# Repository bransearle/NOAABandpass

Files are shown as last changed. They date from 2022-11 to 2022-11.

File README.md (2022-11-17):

# NOAABandpass

A bandpass filter & bias-T powered LNA for receiving APT & LRPT satellite images in the 137MHz region.

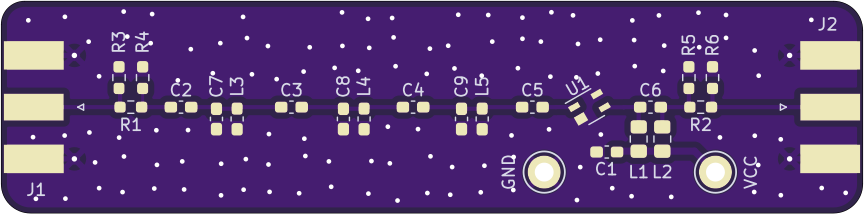
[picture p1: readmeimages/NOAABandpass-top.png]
PCB top side

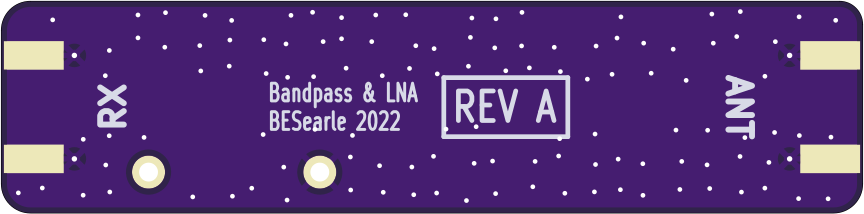
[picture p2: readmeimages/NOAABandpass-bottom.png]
PCB underside


The design uses a 3rd-order Butterworth capacitively-coupled LC resonator filter, followed by a Mini-Circuits MMIC preamp.

Supply voltage is 3V-5V to the bias T. 

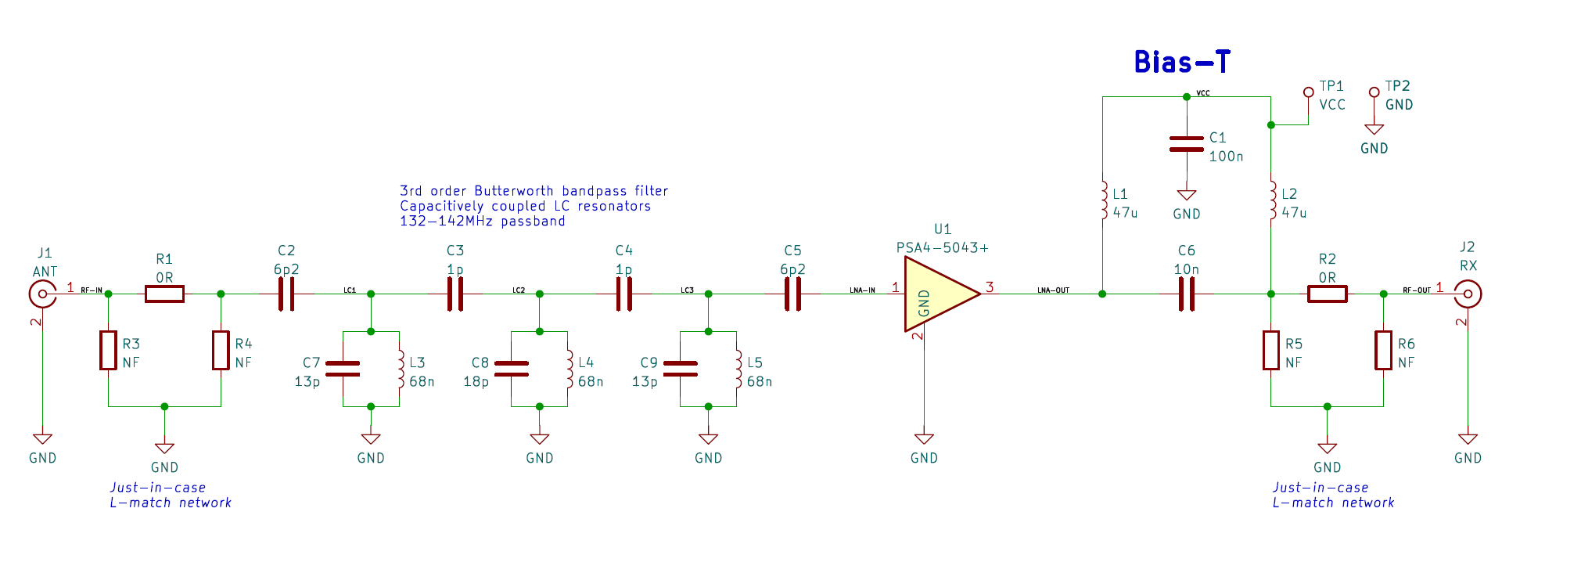
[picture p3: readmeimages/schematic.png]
Schematic

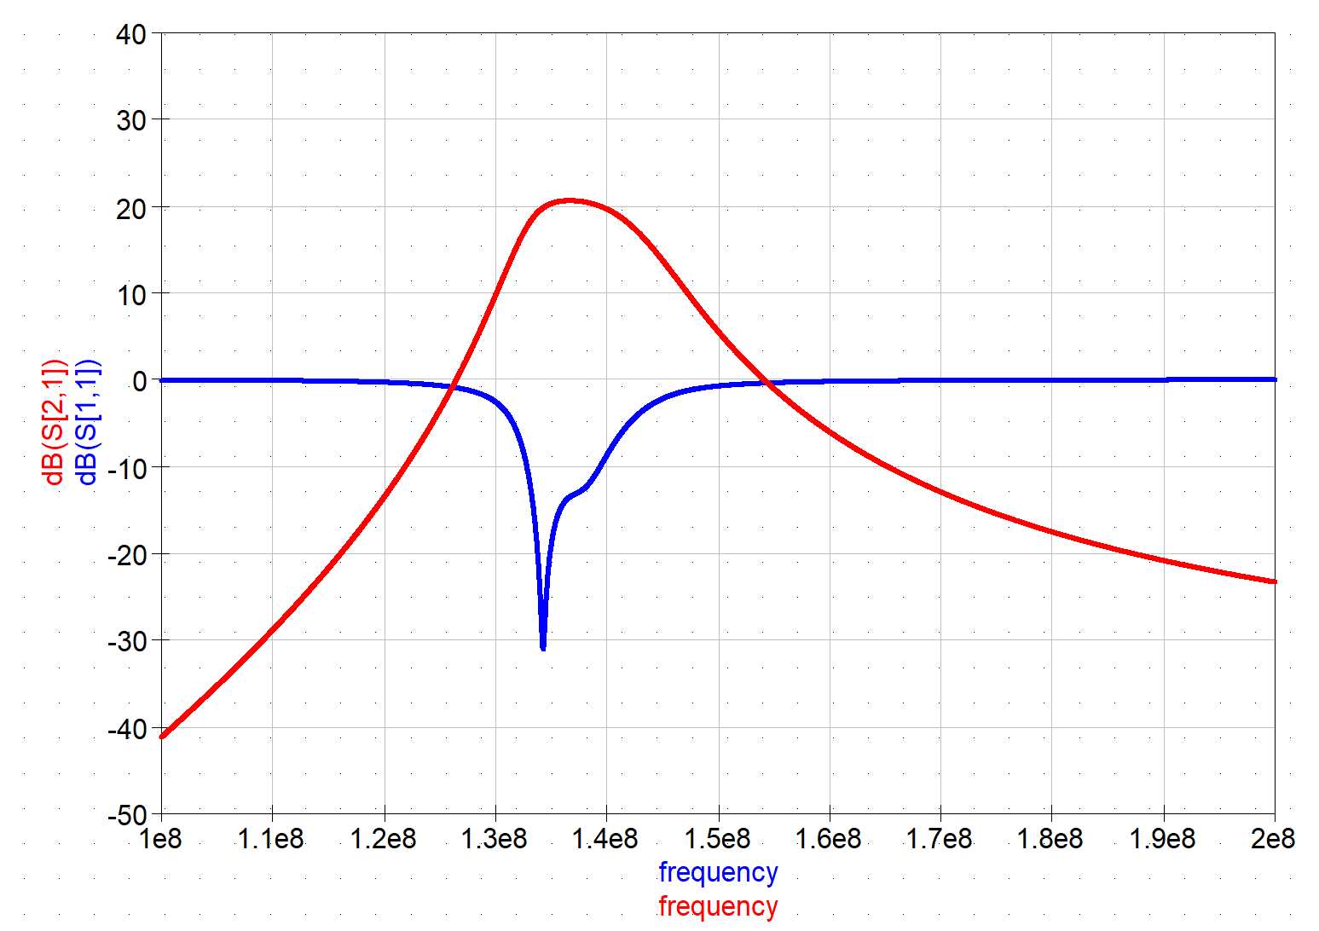
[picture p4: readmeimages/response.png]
Filter response


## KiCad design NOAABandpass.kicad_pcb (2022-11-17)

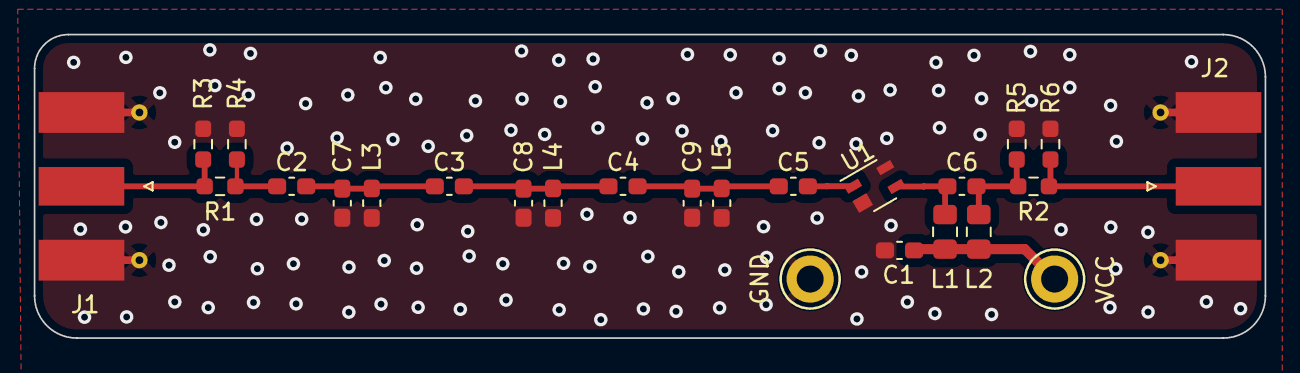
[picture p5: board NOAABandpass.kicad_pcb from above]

Board: 4 copper layers, 73.0 x 18.0 mm, 25 parts (0 on the bottom side), 11 nets.

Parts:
C1: 100n; C_0603_1608Metric_Pad1.08x0.95mm_HandSolder
C2, C5: 6p2; C_0603_1608Metric_Pad1.08x0.95mm_HandSolder
C3, C4: 1p; C_0603_1608Metric_Pad1.08x0.95mm_HandSolder
C6: 10n; C_0603_1608Metric_Pad1.08x0.95mm_HandSolder
C7, C9: 13p; C_0603_1608Metric_Pad1.08x0.95mm_HandSolder
C8: 18p; C_0603_1608Metric_Pad1.08x0.95mm_HandSolder
J1: ANT; SMA_Molex_73251-1153_EdgeMount_Horizontal
J2: RX; SMA_Molex_73251-1153_EdgeMount_Horizontal
L1, L2: 47u; L_0805_2012Metric_Pad1.15x1.40mm_HandSolder
L3, L4, L5: 68n; L_0603_1608Metric_Pad1.05x0.95mm_HandSolder
R1, R2: 0R; R_0603_1608Metric_Pad0.98x0.95mm_HandSolder
R3, R4, R5, R6: NF; R_0603_1608Metric_Pad0.98x0.95mm_HandSolder
TP1: VCC; TestPoint_Keystone_5005-5009_Compact
TP2: GND; TestPoint_Keystone_5005-5009_Compact
U1: PSA4-5043+; Mini-Circuits_MMM1362

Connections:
/LC1: C2.2, C3.1, C7.2, L3.1
/LC2: C3.2, C4.1, C8.2, L4.1
/LC3: C4.2, C5.1, C9.2, L5.1
/LNA-IN: C5.2, U1.1
/LNA-OUT: C6.1, L1.2, U1.3
/RF-IN: J1.1 (In), R1.1, R3.2
/RF-OUT: J2.1 (In), R2.2, R6.2
/VCC: C1.2, L1.1, L2.1, TP1.1 (TP)
GND: C1.1, C7.1, C8.1, C9.1, J1.2 (Ext), J2.2 (Ext), L3.2, L4.2, L5.2, R3.1, R4.1, R5.1, R6.1, TP2.1 (TP), U1.2 (GND), U1.4 (GND)
unnamed: C2.1, R1.2, R4.2
unnamed: C6.2, L2.2, R2.1, R5.2
